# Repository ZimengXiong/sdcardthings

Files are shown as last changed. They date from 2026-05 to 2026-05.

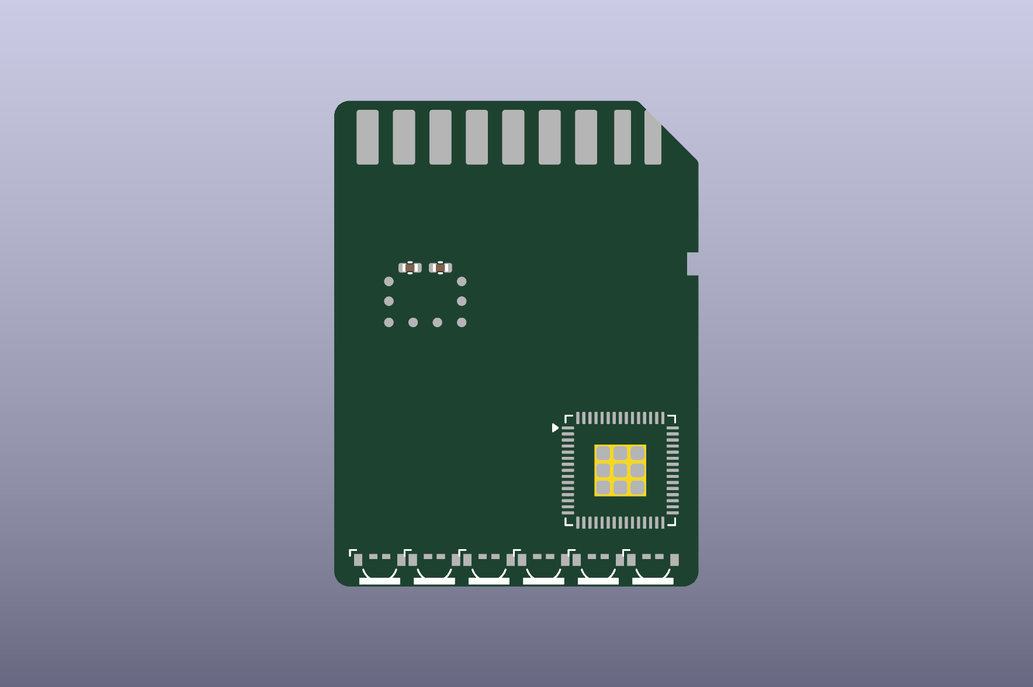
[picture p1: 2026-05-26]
renders/sd-led-card-r21-debug-robot-face.png

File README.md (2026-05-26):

# SD LED Card

SD-card-shaped RGB status module for a MacBook SD slot.

The intended UX is:

1. Insert the card.
2. macOS mounts a tiny volume.
3. Edit `LEDS.TXT` on that volume.
4. Firmware parses the written file and updates the LEDs.

This is not a passive SD adapter. The card has to emulate an SD memory card well
enough for macOS, then intercept block writes to a tiny virtual FAT volume.

## Current Direction

- Controller: RP2350/RP2350A, because PIO can emulate 4-bit SDIO timing.
- SD behavior: fork/adapt `petritoast/pico_sdcard`.
- LED control: low-profile RGB LEDs on the exposed end of the SD card.
- Storage model: virtual FAT volume with a fixed `LEDS.TXT`.
- First hardware: full-size SD card outline, 3.3 V only, no UHS-II.

## Important Constraint

A microcontroller cannot simply "read a file on the SD card" while the Mac is
also using that same SD storage bus. SD is host-owned. To make the file workflow
work smoothly, our MCU should be the SD card: it emulates the block device,
accepts writes from macOS, and updates LEDs when the file content changes.

The alternate approach is a real microSD card plus bus switch, but that usually
requires the Mac to unmount/eject before the MCU can safely read the card. That
is a worse UX for this project.

## Repo Layout

- `docs/architecture.md` - technical plan and tradeoffs.
- `hardware/` - KiCad and hardware notes.
- `firmware/led_config/` - parser for `LEDS.TXT`.
- `firmware/pico_sdcard_upstream/` - upstream SD emulator reference.

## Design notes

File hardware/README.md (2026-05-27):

# Hardware Notes

## First PCB Revision

Build a full-size SD-card-shaped board that is electrically conservative:

- 3.3 V signaling only.
- SD default speed first.
- No UHS-II contacts.
- ENIG edge contacts.
- Low-current LEDs.
- Test pads for SWD/programming.

Current generated PCB status:

- KiCad DRC: clean, 0 violations / 0 unconnected items.
- KiCad ERC: 0 errors. Remaining warnings are library-table/config warnings
  from generated embedded `SDLED` symbols and an intentionally isolated
  `BOOTSEL` debug pad.
- The schematic now captures the intended electrical blocks: SD edge contacts,
  RP2350A, chained addressable side LEDs, capacitive touch, decoupling, and
  SWD/debug pads.
- The current PCB includes a debug-only breakaway probe tail. It extends past
  the exposed end of the SD card and brings the nine SD edge contacts out to
  larger probe pads so host/card behavior can be observed while inserted.
- Components are placed on the same face as the SD contact pads.
- Decorative no-net routing has been removed.
- The remaining production gates are exact LED part/footprint selection, final
  routed copper, exact manufacturer stackup, and confirmed component heights
  for the target MacBook SD slot.

## Mechanical Z Budget

This design is based on KiCad's `SD_Card_Device_16mm_SlotDepth` footprint. That
template models the inserted contact/mechanical region of a full-size SD card.
For the component stack to fit under normal full-size SD thickness, this design
targets a **0.8 mm PCB** rather than the template's original 1.4 mm note.

The current placement keeps component bodies outside that inserted 16 mm region:

| Item | Side | Approx. package height | Mechanical note |
| --- | --- | ---: | --- |
| RP2350A QFN-60 | SD-contact side | 0.90 mm max | About 1.70 mm total on a 0.8 mm PCB. |
| EASV3015RGBA0 right-angle LED | SD-contact side | 1.10 mm max | About 1.90 mm total on a 0.8 mm PCB. |
| 0402 capacitors | SD-contact side | about 0.5 mm | About 1.30 mm total on a 0.8 mm PCB. |
| CT1 capacitive touch electrode | SD-contact side | bare copper | No component height. |
| Debug/test pads | SD-contact side | bare copper | Mechanically safe; no component height. |

The 0.8 mm stack makes the current known package heights fit below the normal
2.1 mm SD-card thickness. This revision intentionally does **not** use a local
stiffener or thickness buildup, because that complicates fabrication. The main
remaining mechanical risk is contact reliability: a 0.8 mm rigid PCB may be
too thin for some SD-slot spring contacts even if it physically inserts cleanly.

The next practical step is a cheap bare-board/mechanical coupon with ENIG edge
pads. Test insertion, removal, pad contact, and whether the side LEDs remain
visible in the target Mac slot before committing to an assembled run.

For bring-up, order the debug-tail Gerbers first. The tail is not part of the
final card; cut or flex off the narrow neck after probing, then lightly smooth
the exposed edge. Do not use the debug-tail board as the final mechanical fit
answer until the snapped edge has been cleaned up and rechecked in the slot.

Run `tools/check_mechanical_envelope.py` after regenerating the board. It fails
if any known package body is placed inside the inserted 16 mm SD-slot region or
if any known board-plus-package stack exceeds normal SD card thickness.

## Candidate Pin Map

This follows the upstream RP2350 SD emulator default:

| Signal | RP2350 GPIO |
| --- | ---: |
| SD CMD | GP0 |
| SD CLK | GP1 |
| SD DAT0 | GP2 |
| SD DAT1 | GP3 |
| SD DAT2 | GP4 |
| SD DAT3 | GP5 |
| LED DATA | GP6 |
| CAP TOUCH | GP7 |

## Mechanical Notes

Use KiCad's SD-card-device footprint as the starting point for outline and edge
pads. The exposed end should contain the LED diffuser windows and any touch
electrode. Keep all components out of the deep-insertion region unless a real
slot-clearance check proves there is room.

The current capacitive touch electrode is `CT1`, a bare copper/ENIG pad on the
SD-contact side near the exposed lip. It should route to `GP7` through the
touch-sensing front end. Keep a local ground guard optional for a later rev:
the first board should prioritize a large accessible touch area and tune
thresholds in firmware.

## BOM Direction

- MCU: RP2350A/RP2350B, final package TBD by routing and thickness.
- LEDs: right-angle / side-view RGB LEDs facing the exposed SD-card lip. A
  top-emitting addressable LED is a poor fit here unless we add a real light
  pipe, because the laptop slot hides most of the top face.
- Decoupling: local 100 nF caps at MCU and LEDs, plus small bulk capacitance.
- Optional ESD: low-capacitance ESD array on exposed SD lines.

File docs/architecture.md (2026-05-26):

# Architecture

## Goal

Expose a small writable SD-card volume to macOS. The user edits `LEDS.TXT`, and
the card updates a row of RGB LEDs without needing a separate USB connection.

## Chosen Architecture

Use an RP2350 as an SD-card device emulator.

MacBook SD slot:

```text
macOS SD host <-> SD edge pads <-> RP2350 PIO SDIO emulator
                                  |
                                  +-> LEDS.TXT block-write parser
                                  |
                                  +-> RGB LED driver
```

The firmware does not need to implement a complete general-purpose SD card. It
only needs to satisfy macOS well enough to mount a small FAT volume and accept
writes to a known config file.

## Why Not a Real MicroSD Card?

A real microSD card plus MCU creates a bus ownership problem:

```text
macOS SD host <-> microSD card
MCU          <-> microSD card
```

Only one controller can own the card at a time. A bus switch can make that safe,
but then the user workflow becomes "write file, eject, wait for MCU to read,
remount." That can work as a fallback prototype, but it is not the intended
seamless file workflow.

## Firmware Plan

1. Start from `petritoast/pico_sdcard`.
2. Keep 3.3 V default-speed SD mode for the first revision.
3. Replace the demo block handler with a tiny virtual FAT volume.
4. Expose one fixed file: `LEDS.TXT`.
5. On `CMD24`/`CMD25` writes, inspect written blocks.
6. When a block contains a valid LED config, parse it and update LEDs.

The first parser is deliberately forgiving. It accepts:

```text
brightness=64
led0=#ff0000
led1=0,255,0
led2=#0040ff
```

## Hardware Plan

Core parts:

- RP2350A or RP2350B MCU.
- 3.3 V rail from SD `VDD`.
- 6 SDIO pins: `CMD`, `CLK`, `DAT0`, `DAT1`, `DAT2`, `DAT3`.
- 5-7 low-profile RGB LEDs at the exposed edge.
- Optional capacitive touch pad on exposed edge plating.
- Programming pads/SWD or BOOT/USB breakout for firmware loading.

The first PCB should intentionally ignore UHS-II rear-row pins. It should behave
as a 3.3 V default-speed SD card.

## Main Risks

- macOS may be stricter than the USB reader used by the upstream emulator.
- The SD slot may power-manage the card aggressively.
- Full SD-card thickness leaves almost no component clearance.
- macOS writes hidden metadata files; firmware should tolerate extra writes.
- In-slot LED current must be low to avoid heat and brownouts.

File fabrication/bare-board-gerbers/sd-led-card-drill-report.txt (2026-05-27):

Drill report for sd-led-card.kicad_pcb
Created on 2026-05-26T23:57:00

Copper Layer Stackup:
    =============================================================
    L1 :  F.Cu                      front
    L2 :  B.Cu                      back

Drill file 'sd-led-card.drl' contains
    plated through holes:
    =============================================================

    Total plated holes count 0

Not plated through holes are merged with plated holes
    unplated through holes:
    =============================================================

    Total unplated holes count 0

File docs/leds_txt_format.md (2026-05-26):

# `LEDS.TXT` Format

The config is line-oriented ASCII.

```text
brightness=64
led0=#ff0000
led1=#00ff00
led2=#0000ff
led3=255,128,0
led4=12,12,12
led5=off
```

Rules:

- `brightness` is 0-255.
- LED keys are `led0`, `led1`, etc.
- Colors can be hex (`#rrggbb`) or decimal CSV (`r,g,b`).
- `off` means `0,0,0`.
- Unknown lines are ignored.
- Whitespace around keys and values is allowed.

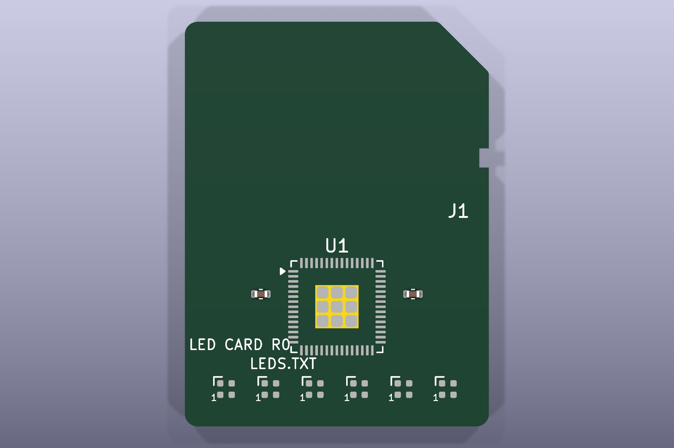
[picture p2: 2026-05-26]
renders/sd-led-card-r1-top-clear.png

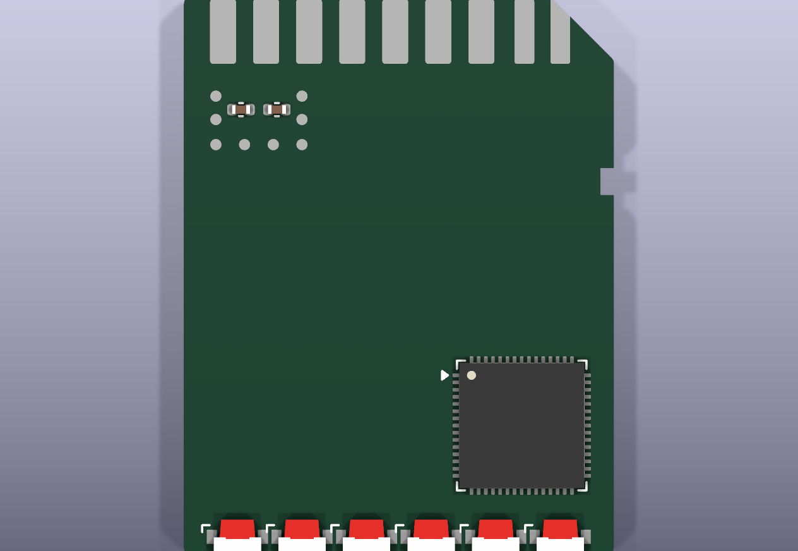
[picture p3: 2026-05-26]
renders/sd-led-card-r27-leds-closer-top.png

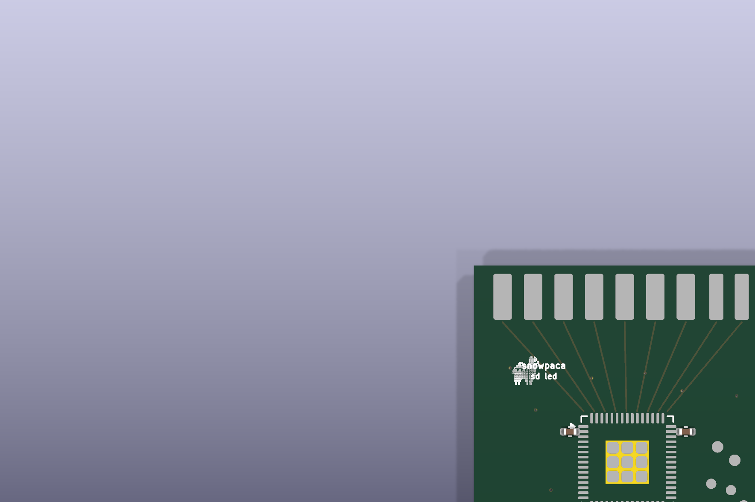
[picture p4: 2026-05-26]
renders/sd-led-card-r5-clean-top.png

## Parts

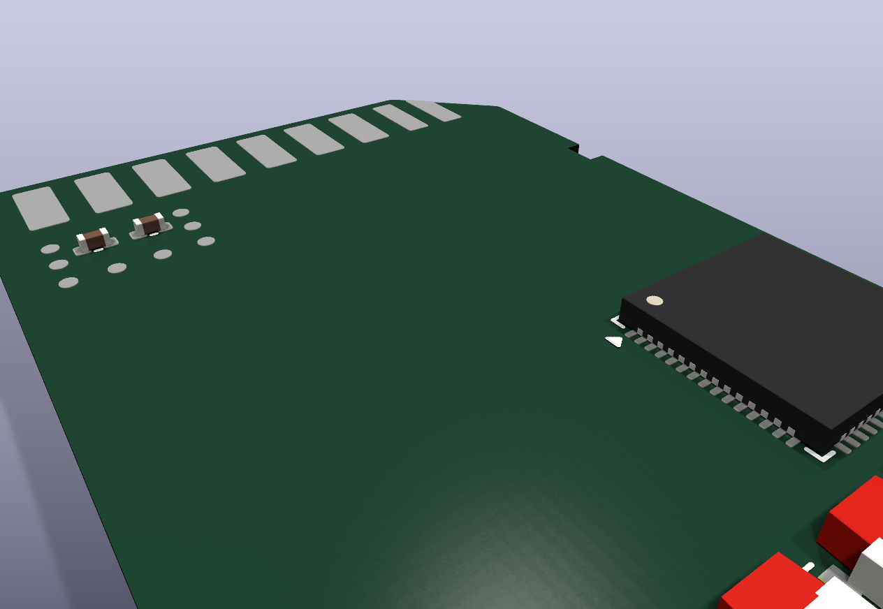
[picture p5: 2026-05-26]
renders/sd-led-card-r25-robot-up-actual-parts.png

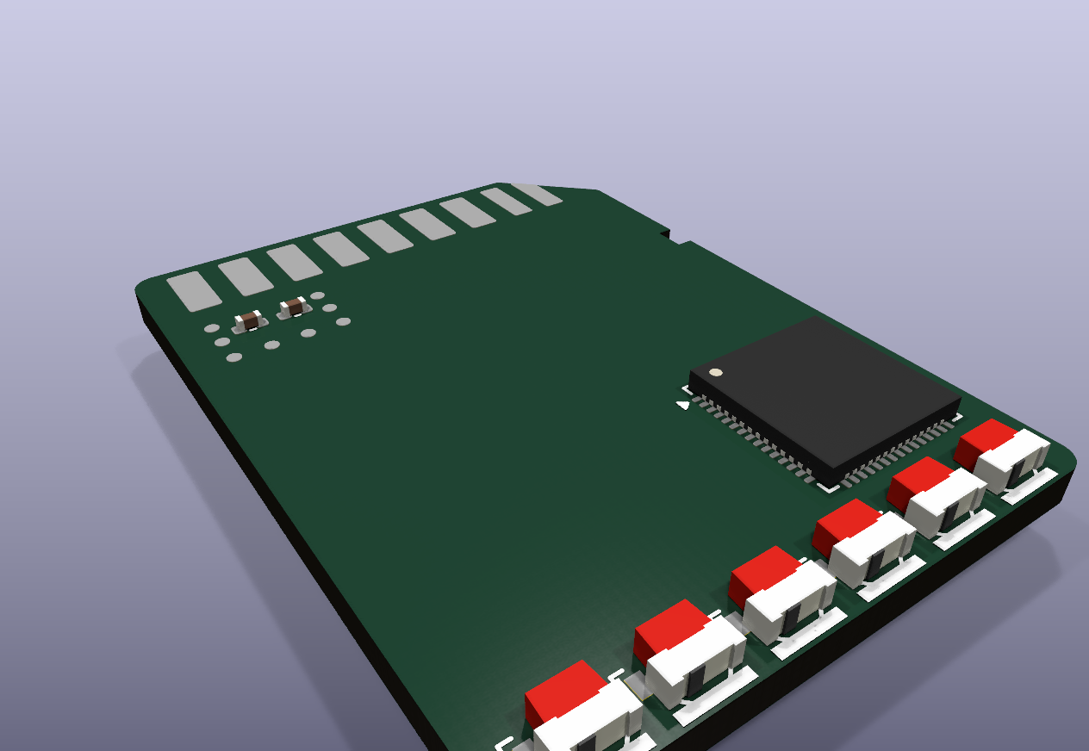
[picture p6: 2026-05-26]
renders/sd-led-card-r26-full-actual-parts.png

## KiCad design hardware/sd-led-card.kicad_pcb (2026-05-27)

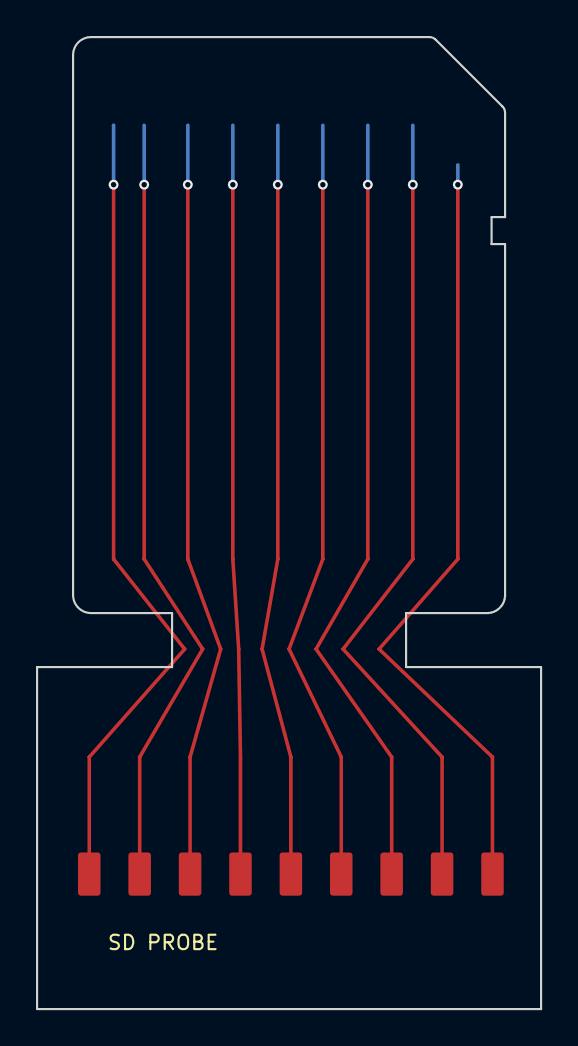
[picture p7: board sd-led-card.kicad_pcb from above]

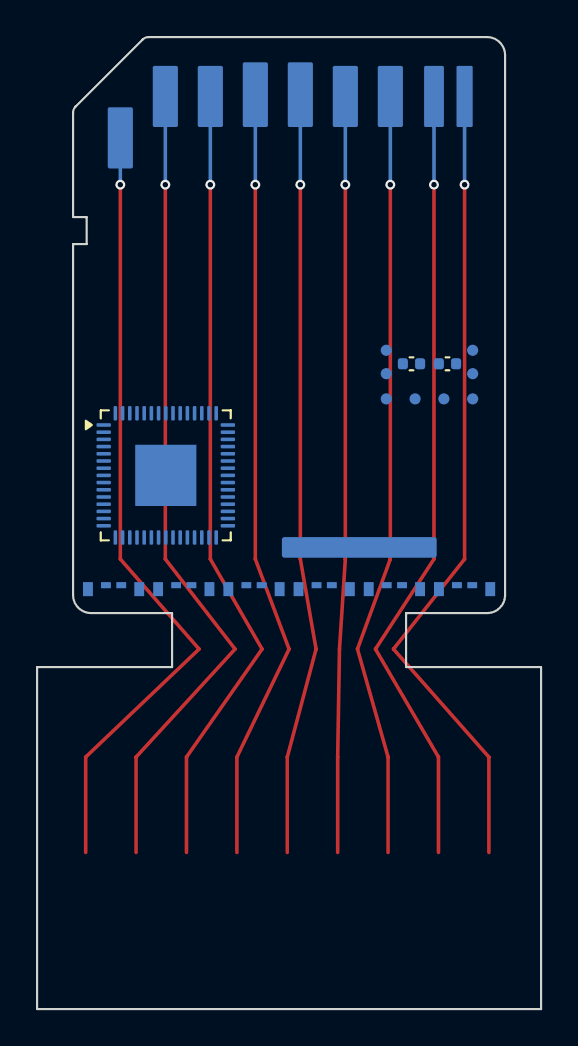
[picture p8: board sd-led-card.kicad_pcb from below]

Board: 2 copper layers, 28.0 x 54.0 mm, 13 parts (11 on the bottom side), 9 nets.

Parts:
C1: 100n; C_0402_1005Metric
C2: 1u; C_0402_1005Metric
CT1: CT1
D1, D2, D3, D4, D5, D6: EASV3015 side RGB; LED_RGB_Everlight_EASV3015RGBA0_Horizontal
DBG1: SWD/debug pads
J1: SD card edge contacts; SD_Card_Device_16mm_SlotDepth
J2: breakaway SD probe pads
U1: RP2350A; QFN-60-1EP_7x7mm_P0.4mm_EP3.4x3.4mm

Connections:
+3V3: J1.4, J2.4
GND: J1.6, J2.6
SD_CLK: J1.5, J2.5
SD_CMD: J1.3, J2.3
SD_DAT0: J1.7, J2.7
SD_DAT1: J1.8, J2.8
SD_DAT2: J1.1, J2.1
SD_DAT3: J1.2, J2.2
SD_VSS2: J1.9, J2.9

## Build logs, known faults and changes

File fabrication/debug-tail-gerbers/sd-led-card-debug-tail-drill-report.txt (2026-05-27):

Drill report for sd-led-card.kicad_pcb
Created on 2026-05-27T00:10:38

Copper Layer Stackup:
    =============================================================
    L1 :  F.Cu                      front
    L2 :  B.Cu                      back

Drill file 'sd-led-card.drl' contains
    plated through holes:
    =============================================================
    T1  0.300mm  0.0118"  (9 holes))

    Total plated holes count 9

Not plated through holes are merged with plated holes
    unplated through holes:
    =============================================================

    Total unplated holes count 0

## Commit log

2026-05-26 Initial SD LED card design
    [sd-led-card.kicad_pcb, sd-led-card.kicad_sch]
2026-05-26 Move edge LEDs closer
    [sd-led-card.kicad_pcb]
2026-05-26 Rebase layout on SD card footprint
    [sd-led-card.kicad_pcb]
2026-05-26 Add SD slot height envelope check
2026-05-26 Target thin PCB for SD slot fit
    [sd-led-card.kicad_pcb]
2026-05-26 Document SD slot stiffener envelope
    [sd-led-card.kicad_pcb]
2026-05-27 Add functional schematic scaffold
    [sd-led-card.kicad_pcb, sd-led-card.kicad_sch]
2026-05-27 Remove contact stiffener assumption
    [sd-led-card.kicad_pcb]
2026-05-27 Add bare board Gerber package
    [sd-led-card-B_Cu.gbl, sd-led-card-B_Fab.gbr, sd-led-card-B_Mask.gbs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]
2026-05-27 Add breakaway SD probe tail
    [sd-led-card-B_Cu.gbl, sd-led-card-B_Fab.gbr, sd-led-card-B_Mask.gbs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]
